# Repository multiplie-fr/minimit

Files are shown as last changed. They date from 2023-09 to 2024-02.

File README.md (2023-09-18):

# minimit

<pre>
  //////////////////////////////////////////////////////////////////////////////
//             _       _           _ _                                       //
//            (_)     (_)         (_) |                                      //
//   _ __ ___  _ _ __  _ _ __ ___  _| |_                                     //
//  | '_ ` _ \| | '_ \| | '_ ` _ \| | __|                                    //
//  | | | | | | | | | | | | | | | | | |_    multiplié multiplié.fr          //
//  |_| |_| |_|_|_| |_|_|_| |_| |_|_|\__|   by cécile adam & pascale moise   //
//                                                                           //
///////////////////////////////////////////////////////////////////////////////
</pre>

Le MiniMit permet de redonner vie à votre bon vieux Minitel

On trouvera ici :
- le schéma et les fichiers Gerber de la carte électronique
- les fichiers STEP du boitier
- le code source du firmware est dans le repository [Minimit-beta](https://github.com/multiplie-fr/minimit-beta) (parce qu'il est encore un peu rough !)
- les scripts PHP que l'on utilise sur un serveur distant pour faciliter les développements (ça, ça arrivera un peu plus tard)

https://multiplié.fr/fr/1-3/objets/minimit

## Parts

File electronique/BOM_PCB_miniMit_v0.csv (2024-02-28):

ID | Name | Designator | Footprint | Quantity | Manufacturer Part | Manufacturer | Supplier | Supplier Part
1 | Header-Male-2.54_1x6 | PROG | HDR-TH_6P-P2.54-V-M-1 | 1 | 2.54-1x6P直针 | BOOMELE(博穆精密) | LCSC | C37208
2 | 1K | R2,R1 | R0402 | 2 | 0402WGF1001TCE | UniOhm | LCSC | C11702
3 | 1uF | C8 | C0603 | 1 | CL10A105KB8NNNC | SAMSUNG | LCSC | C15849
4 | 100nF | C9,C2 | C0603 | 2 | CC0603KRX7R9BB104 | YAGEO | LCSC | C14663
5 | RED | LED1 | LED0603-R-RD | 1 | 19-217/R6C-AL1M2VY/3T | EVERLIGHT(亿光) | LCSC | C72044
6 | GREEN | LED2 | LED0603-RD | 1 | 19-217/GHC-YR1S2/3T | EVERLIGHT(亿光) | LCSC | C72043
7 | 10uF | C1 | C0603 | 1 | CL10A106KP8NNNC | SAMSUNG | LCSC | C19702
8 | JST-2.54-4P | MINITEL | CONN-SMD_2.54-4P-WT | 1 | - | Boom Precision Elec | LCSC | C146120
9 | 100 | R3,R5 | R0402 | 2 | 0402WGF1000TCE | UniOhm | LCSC | C25076
10 | 10K | R6,R8,R9 | R0402 | 3 | 0402WGF1002TCE | UniOhm | LCSC | C25744
11 | 20K | R7 | R0402 | 1 | 0402WGF2002TCE | UniOhm | LCSC | C25765
12 | 22uF | CB2 | C1206 | 1 | CL31B226KPHNNNE | SAMSUNG | LCSC | C87996
13 | 10nF | CBB | C0603 | 1 | 0603B103K500NT | FH | LCSC | C57112
14 | ESP32-WROVER-E(8MB)_C701348 | U3 | WIFI-SMD_ESP32-WROVER-E | 1 | ESP32-WROVER-E-N8R8 | ESPRESSIF(乐鑫) | LCSC | C701348
15 | 56K | R4 | R0402 | 1 | 0402WGF5602TCE | UniOhm | LCSC | C25796
16 | SS14 | D1 | SMA_L4.4-W2.8-LS5.4-RD | 1 | SS14 | MDD | LCSC | C2480
17 | AP3211KTR-G1 | U2 | SOT-23-6_L2.9-W1.6-P0.95-LS2.8-BR | 1 | AP3211KTR-G1 | DIODES | LCSC | C154863
18 | 1N4148WS T4 | D2 | SOD-323_L1.8-W1.3-LS2.5-RD | 1 | 1N4148WS T4 | CJ | LCSC | C2128
19 | 10uF | CB1 | C0805 | 1 | CL21A106KAYNNNE | SAMSUNG | LCSC | C15850
20 | nSMD025 | F1 | F1206 | 1 | nSMD025 | TECHFUSE | LCSC | C70068
21 | 4.7uH | L1 | IND-SMD_L4.4-W4.2 | 1 | MWSA0402S-4R7MT | Sunlord | LCSC | C408337
22 | S8050 | Q1 | SOT-23-3_L3.0-W1.7-P0.95-LS2.9-BR | 1 | S8050 | CJ | LCSC | C2146
23 | 49.9K | RB1 | R0603 | 1 | 0603WAF4992T5E | UniOhm | LCSC | C23184
24 | 16.2K | RB2 | R0603 | 1 | 0603WAF1622T5E | UniOhm | LCSC | C22885
25 | 100K | RB3 | R0402 | 1 | 0402WGF1003TCE | UniOhm | LCSC | C25741

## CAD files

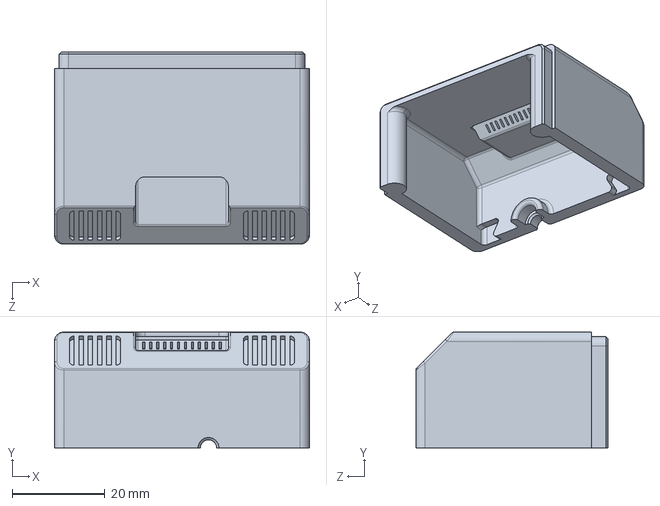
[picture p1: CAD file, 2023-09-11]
mecanique/V3/Demi boitier supérieurV3.STEP
55.0 x 25.0 x 41.5 mm

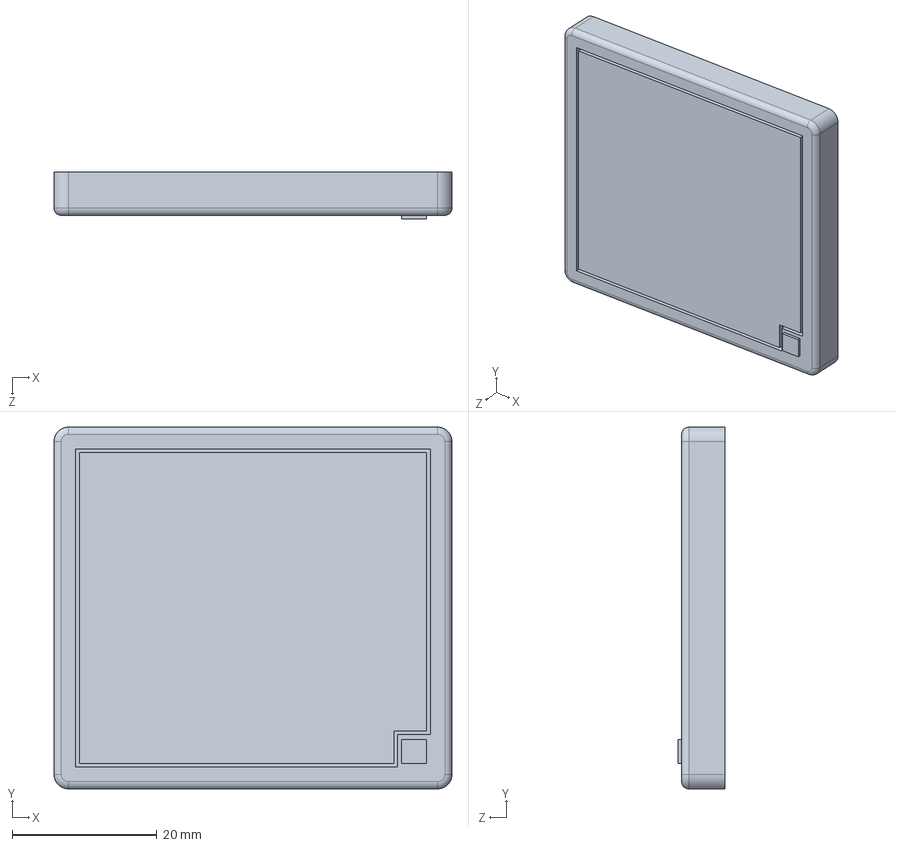
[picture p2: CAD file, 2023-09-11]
mecanique/V3/Face avant boitierV3_PRESTA3D.STEP
55.0 x 50.0 x 6.50 mm

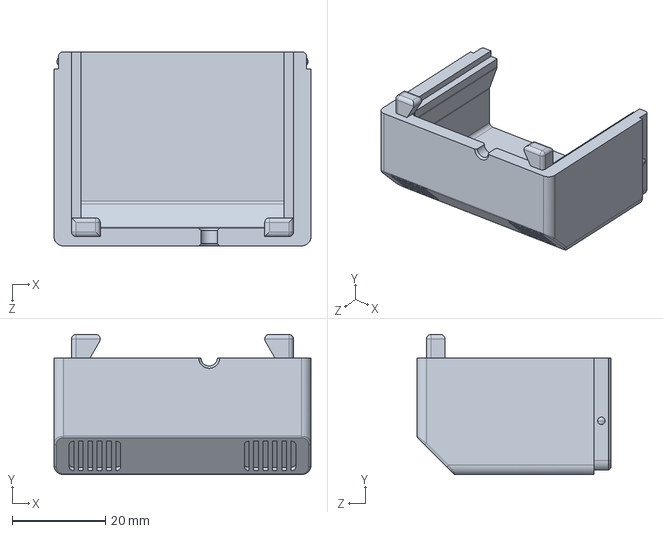
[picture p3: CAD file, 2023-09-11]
mecanique/V3/Demi boitier inférieurV3.STEP
55.0 x 30.0 x 41.5 mm

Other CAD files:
mecanique/V3/Demi boitier inférieurV3.STL
mecanique/V3/Demi boitier supérieurV3.STL
mecanique/V3/Face avant boitierV3_PRESTA3D.STL

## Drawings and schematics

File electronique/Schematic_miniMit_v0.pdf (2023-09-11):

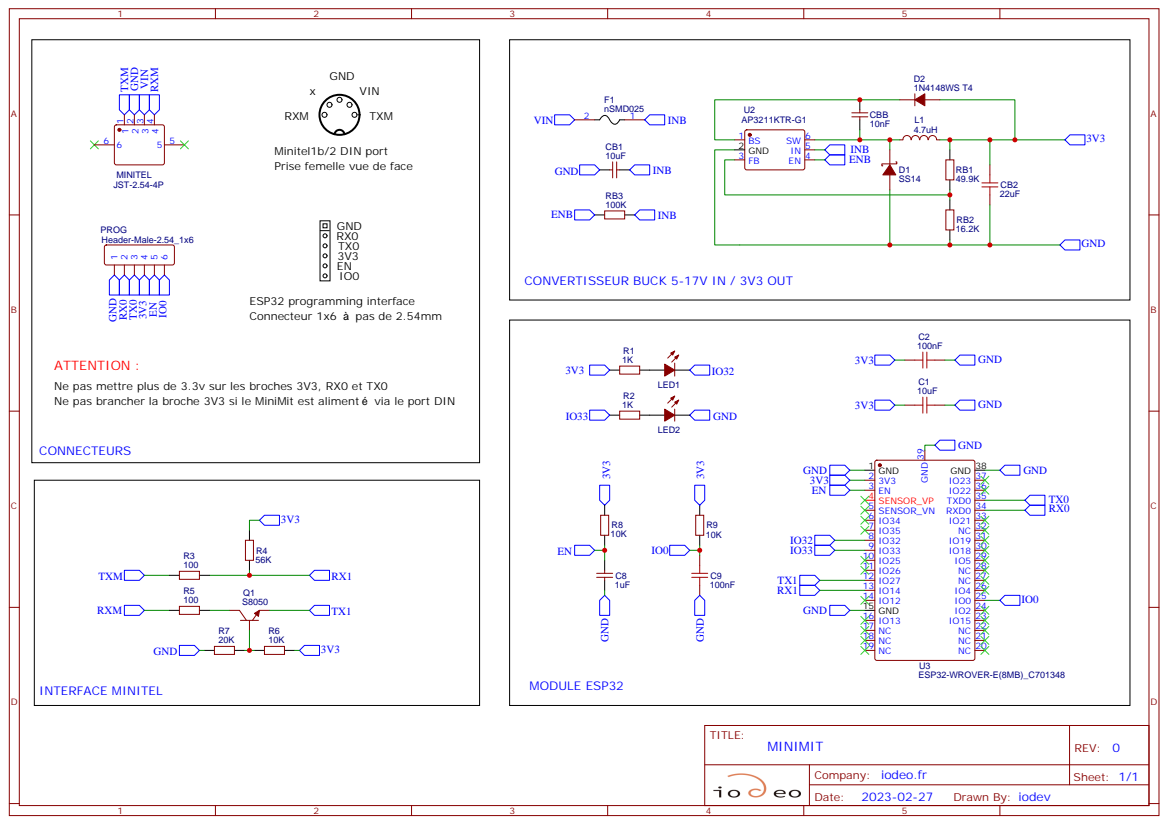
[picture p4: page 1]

Minitel1b/2 DIN port
Prise femelle vue de face

CONVERTISSEUR BUCK 5-17V IN / 3V3 OUT

ATTENTION :
Ne pas mettre plus de 3.3v sur les broches 3V3, RX0 et TX0
Ne pas brancher la broche 3V3 si le MiniMit est aliment via le port DIN

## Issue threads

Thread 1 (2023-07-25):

0 est un élément absorbant pour la multiplication

tobozo, 2023-07-25:
On trouvera ici :

        le schéma et les fichiers Gerber de la carte électronique
        les fichiers STEP du boitier
        le code source du firmware s'exécutant sur l'ESP32 (Arduino sketches)
        les scripts PHP que l'on utilise sur un serveur distant pour faciliter les développements

coucou,

à défaut d'honorer le contenu actuel du readme, pouvez vous y ajouter quelques liens afin de permettre aux heureux acquéreurs de cette petite merveille d'en personnaliser le comportement ?

voici quelques exemples trouvés en entrant "minitel esp32" dans github search :

https://github.com/iodeo/Minitel-ESP32
https://github.com/iodeo/Socketel
https://github.com/bill-of-materials/awesome-minitel

PierrickP, 2023-09-11:
Je :+1:
On aimerait bien le logiciel, mais également la doc hardware pour faire une alimentation externe pour le Minitel 1

valguenichon, 2023-09-18:
J'adorerais fabriquer moi-même ce projet, pour le plaisir de faire, mais c'est un chouille obscur pour moi même si pratique l'électronique amusante ;-)
Je n'arrive pas vraiment à faire le lien entre la doc électronique et le PCB
Peut-être que ça viendra avec le temps, en tout cas j'adore.

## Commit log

2023-09-11 Ajout des repertoires electronique et mecanique
    [Demi boitier inférieurV3.STEP, Demi boitier inférieurV3.STL, Demi boitier supérieurV3.STEP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]
2024-02-28 Added BOM
    [BOM_PCB_miniMit_v0.csv]
